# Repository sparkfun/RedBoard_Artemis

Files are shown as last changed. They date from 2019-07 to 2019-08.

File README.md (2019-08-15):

SparkFun RedBoard Artemis
============================

SparkFun RedBoard Artemis  
[*SparkFun RedBoard (DEV-15444)*](https://www.sparkfun.com/products/15444)

Think of the RedBoard Artemis as just another Arduino... That has BLE. And one meg of flash. And runs at less than 1mA. Oh, and it can run TensorFlow models. Ya, that too. The RedBoard Artemis takes the incredibly powerful Artemis module from SparkFun and wraps it up in an easy to use and familiar Uno footprint. We've written an Arduino core from scratch to make programming the Artemis as familiar as `Serial.begin(9600)`. Time-to-first-blink is less than five minutes.

The RedBoard Artemis has the improved power conditioning and USB to serial that we've refined over the years on our RedBoard line of products. A modern USB-C connector makes programming easy. A Qwiic connector makes I<sup>2</sup>C easy. The RedBoard Artemis is fully compatible with SparkFun's Arduino core and can be programmed easily under the Arduino IDE. We've exposed the JTAG connector for more advanced users who prefer to use the power and speed of professional tools. We've added a digital MEMS microphone for folks wanting to experiment with always-on voice commands with TensorFlow and machine learning. We've even added a convenient jumper to measure current consumption for low power testing.

With 1M flash and 384k RAM you'll have plenty of room for your sketches. The Artemis module runs at 48MHz with a 96MHz turbo mode available and with Bluetooth to boot!

The SparkFun RedBoard Artemis is a great platform to 'kick the tires' of this amazing module. If you're interesting in testing out the full capabilities of the SparkFun Artemis module or if you're looking for more compact solution, be sure to checkout our ATP and Nano versions of the Artemis line.

Repository Contents
-------------------
* **/Hardware** - Eagle design files (.brd, .sch)

Documentation
-------------------
* **[Hookup Guide for the RedBoard Artemis](https://learn.sparkfun.com/tutorials/hookup-guide-for-the-sparkfun-redboard-artemis)**
* **[Artemis Development with Arduino](https://learn.sparkfun.com/tutorials/artemis-development-with-arduino)**
* **[Ambiq Apollo3 SDK SetUp](https://learn.sparkfun.com/tutorials/using-sparkfun-edge-board-with-ambiq-apollo3-sdk)**
* **[Designing with the SparkFun Artemis](https://learn.sparkfun.com/tutorials/designing-with-the-sparkfun-artemis)**
* **[CH340E USB to serial IC Drivers](https://www.sparkfun.com/ch340)**

License Information
-------------------

This product is _**open source**_! 

Please review the LICENSE.md file for license information. 

If you have any questions or concerns on licensing, please contact techsupport@sparkfun.com.

Please use, reuse, and modify these files as you see fit. Please maintain attribution to SparkFun Electronics and release any derivative under the same license.

Distributed as-is; no warranty is given.

- Your friends at SparkFun.

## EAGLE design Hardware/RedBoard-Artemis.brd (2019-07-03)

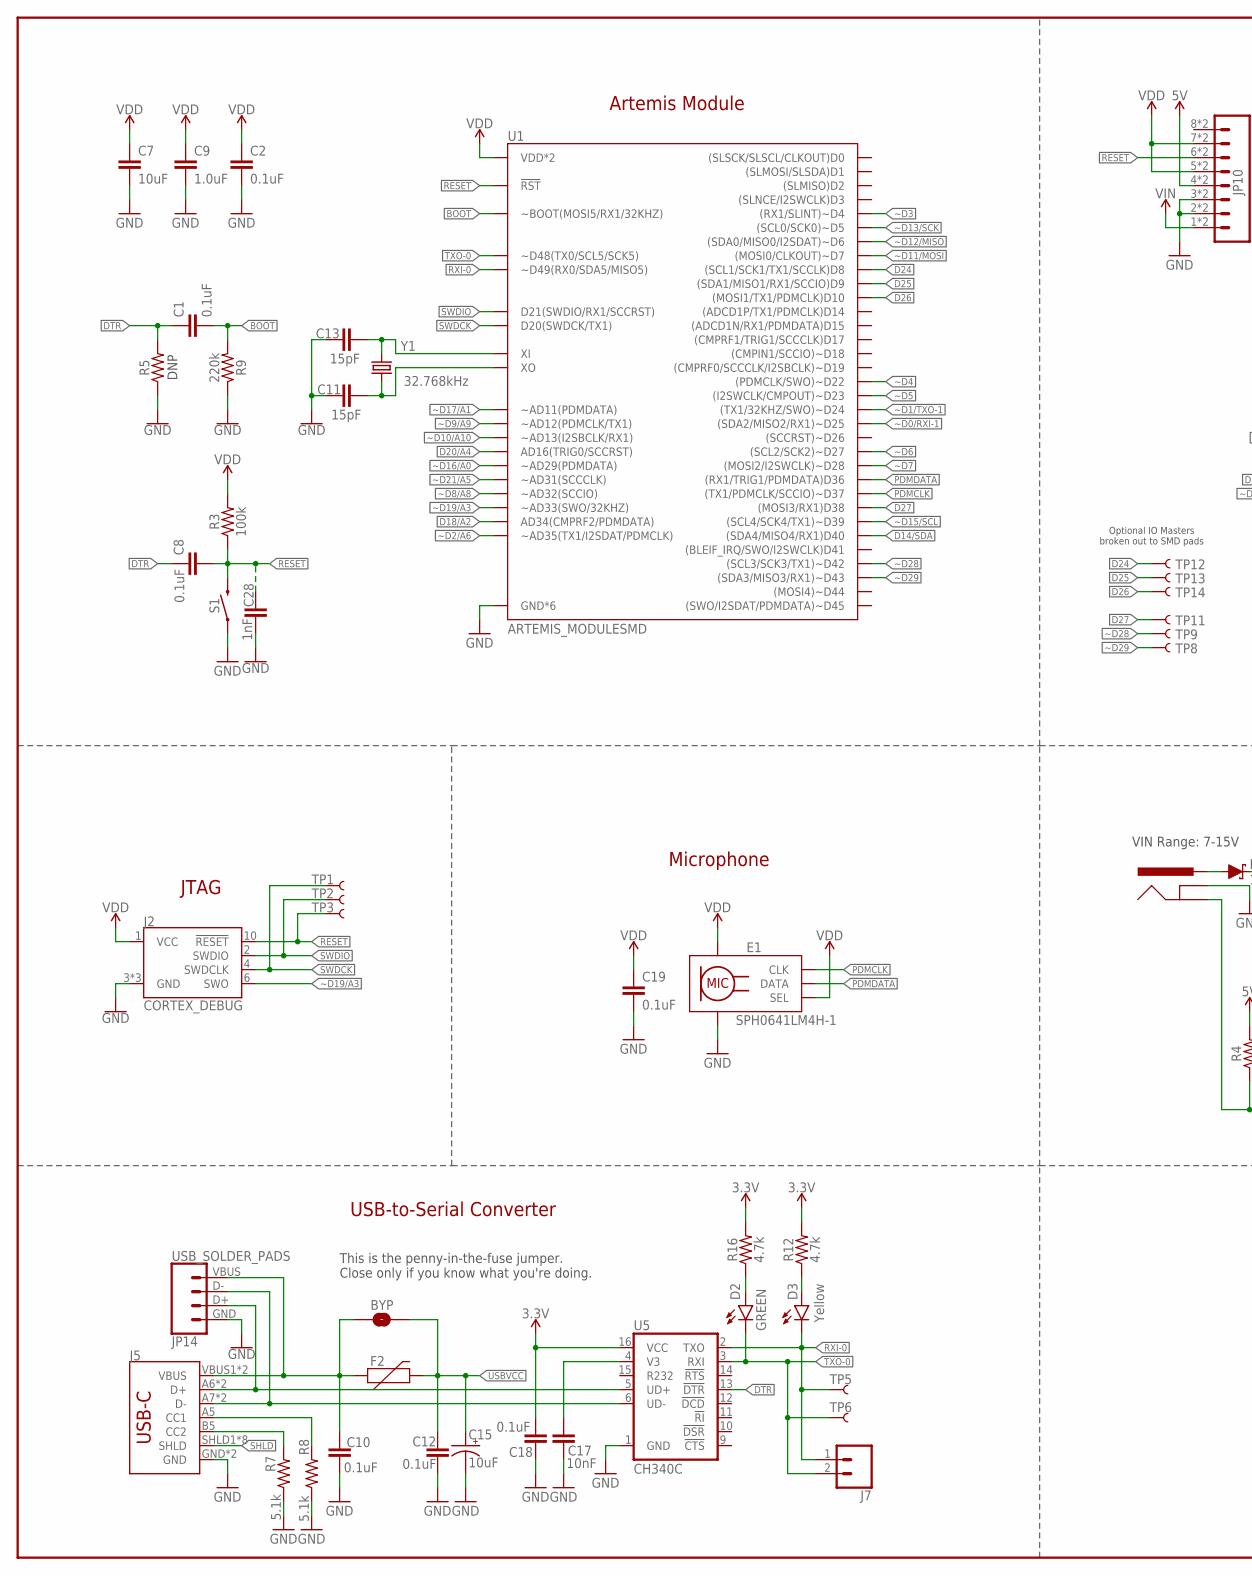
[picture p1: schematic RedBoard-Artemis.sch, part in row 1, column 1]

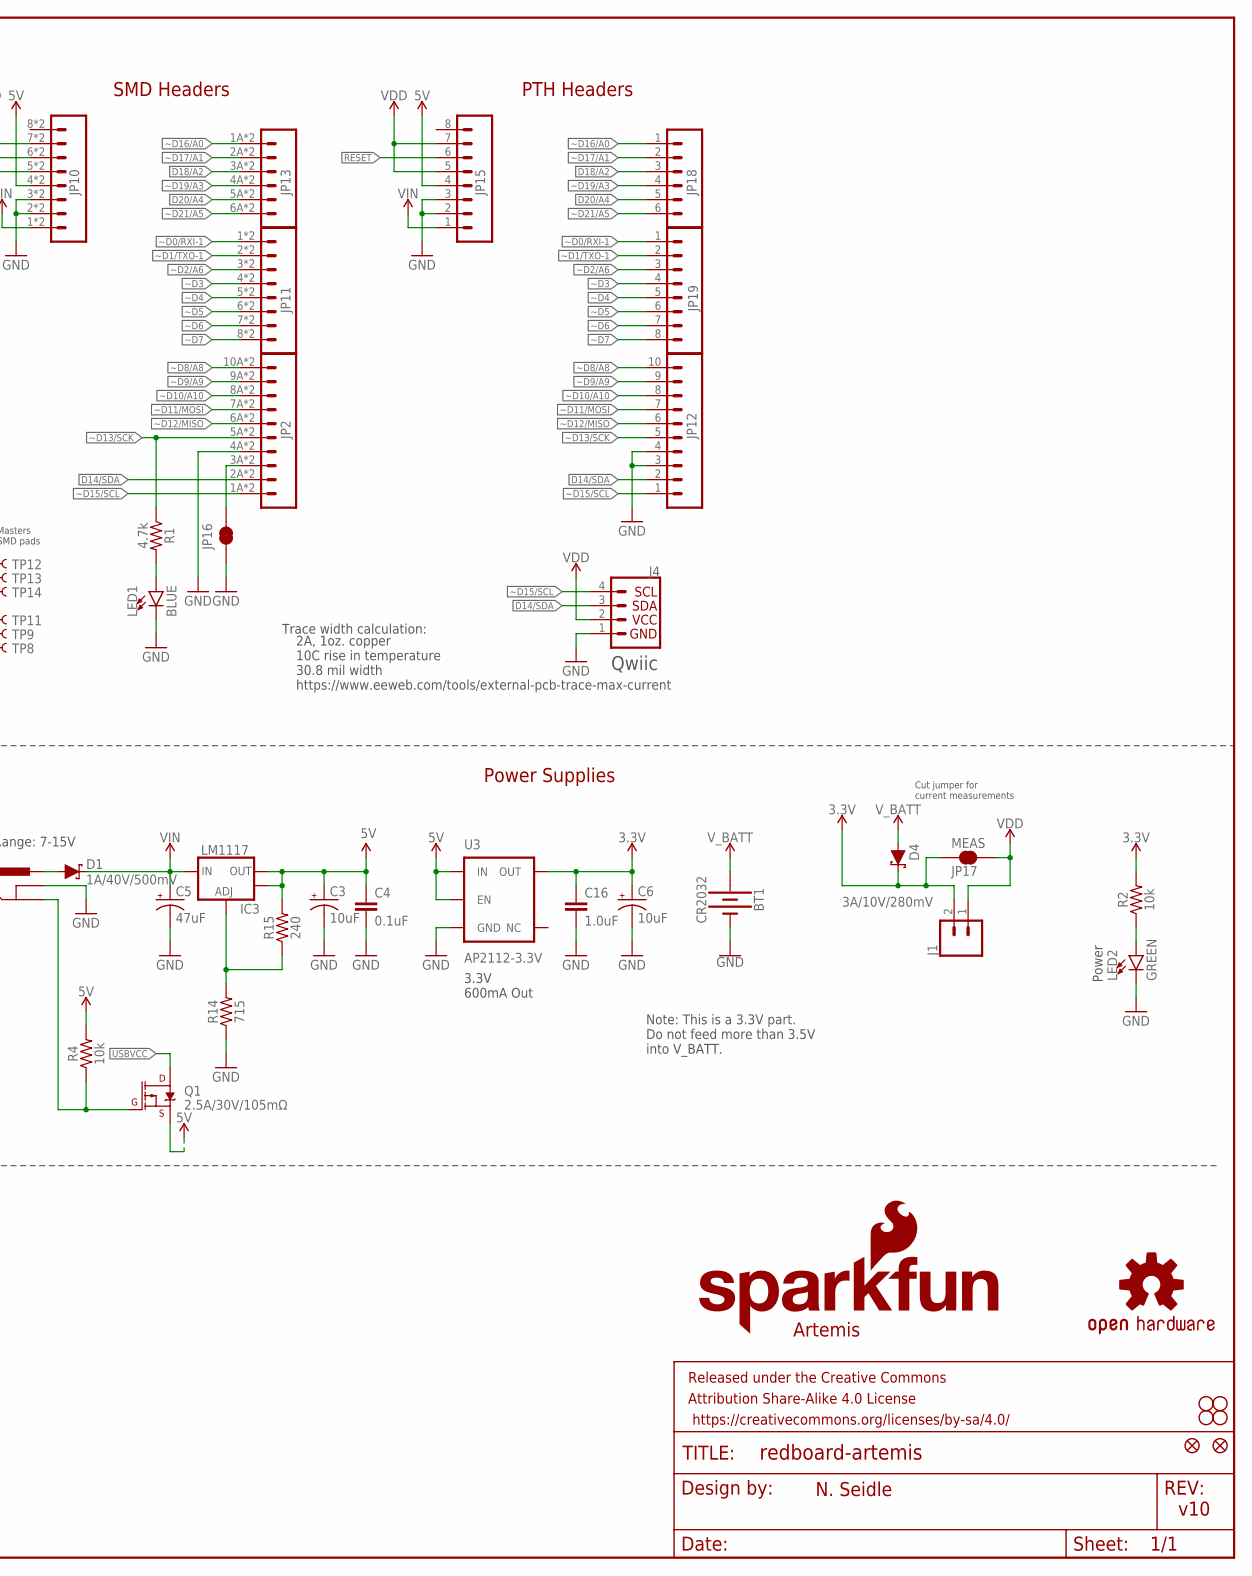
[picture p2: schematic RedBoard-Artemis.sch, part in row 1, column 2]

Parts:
BT1: CR2032; BATTCON_20MM_4LEGS_OVERPASTE
BYP: JUMPER-SMT_2_NO_SILK; SMT-JUMPER_2_NO_SILK
C1, C2, C4, C8, C10, C12, C18, C19: 0.1uF; 0603
C3, C6, C15: 10uF; EIA3216
C5: 47uF; PANASONIC_D
C7: 10uF; 0603
C9, C16: 1.0uF; 0603
C11, C13: 15pF; 0603
C17: 10nF; 0603
C28: 1nF; 0603
D1: 1A/40V/500mV; SMA-DIODE
D2: GREEN; LED-1206
D3: Yellow; LED-1206
D4: 3A/10V/280mV; SOD-323
E1: SPH0641LM4H-1; SPH0641LM4H-1_MICROPHONE
F2: 6V/2A; 1210
FRAME3: FRAME-LEDGER; CREATIVE_COMMONS
IC3: LM1117; SOT223-ALT1
J1, J7: CONN_021X02_NO_SILK; 1X02_NO_SILK
J2: CORTEX_DEBUG; 2X5-PTH-1.27MM-NO_SILK
J3: POWER_JACKTOE; POWER_JACK_SMD_OVERPASTE_TOE
J4: QWIIC_CONNECTORJS-1MM; JST04_1MM_RA
J5: USB-C; USB-C-16P
JP1: SFE_LOGO_NAME.1_INCH; SFE_LOGO_NAME_.1
JP2: M10SMD_COMBO; 1X10_SMD_COMBINED
JP3, JP4, JP5, JP6: STAND-OFF
JP7: SFE_LOGO_FLAME.1_INCH; SFE_LOGO_FLAME_.1
JP8, JP9: FIDUCIAL1X2; FIDUCIAL-1X2
JP10: CONN_08SMD-COMBO-FEMALE_NC; 1X08_SMD_COMBINED_NC
JP11: JP11; 1X08_SMD_COMBINED_NC
JP12: M10NO_SILK; 1X10_NO_SILK
JP13: M06SMD-STRAIGHT-COMBO; 1X06_SMD_STRAIGHT_COMBO
JP14: USB_SOLDER_PADS; USB-SOLDER-PADS
JP15: M08NO_SILK; 1X08_NO_SILK@1
JP16: JUMPER-SMT_2_NC_TRACE_SILK; SMT-JUMPER_2_NC_TRACE_SILK
JP17: MEAS; SMT-JUMPER_2_NC_TRACE_SILK
JP18: M06NO_SILK; 1X06_NO_SILK@1
JP19: CONN_08NO_SILK_FEMALE_PTH; 1X08_NO_SILK
LED1: BLUE; LED-1206
LED2: GREEN; LED-1206
Q1: 2.5A/30V/105mΩ; SOT23-3
R1, R12, R16: 4.7k; 0603
R2, R4: 10k; 0603
R3: 100k; 0603
R5: 0603
R7, R8: 5.1k; 0603
R9: 220k; 0603
R14: 715; 0603
R15: 240; 0603
S1: MOMENTARY-SWITCH-SPST-SMD-5.2-TALL-REDUNDANT; TACTILE_SWITCH_SMD_5.2MM
TP1, TP2, TP3, TP5, TP6, TP8, TP9, TP11, TP12, TP13, TP14: TEST-POINT3X5; PAD.03X.05
U1: ARTEMIS_MODULESMD; ARTEMIS_FP
U3: AP2112-3.3V; SOT23-5
U5: CH340C; SO016
U$16: OSHW-LOGOS; OSHW-LOGO-S
Y1: 32.768kHz; CRYSTAL-SMD-3.2X1.5MM

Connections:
3.3V: C6.+, C16.1, C18.1, D4.C, J1.2, JP17.1, R2.2, R12.2, R16.2, U3.5 (OUT), U5.16 (VCC)
5V: C3.+, C4.1, IC3.2 (OUT), IC3.4 (OUT), JP10.4, JP10.4@2 (4), JP15.4, Q1.2 (S), R4.2, R15.2, U3.1 (IN), U3.3 (EN)
!DTR: C1.1, C8.1, R5.2, U5.13 (!DTR)
!RESET: C8.2, C28.1, J2.10 (!RESET), JP10.6, JP10.6@2 (6), JP15.6, R3.1, S1.3 (2), S1.4 (2), TP3.P$1, U1.~RST (!RST)
BOOT: C1.2, R9.2, U1.BOOT (~BOOT(MOSI5/RX1/32KHZ))
CC1: J5.A5 (CC1), R8.2
CC2: J5.B5 (CC2), R7.2
D14/SDA: J4.3, JP2.2A (2), JP2.2B (2), JP12.2, U1.D40 ((SDA4/MISO4/RX1)D40)
D18/A2: JP13.3A (3), JP13.3B (3), JP18.3, U1.AD34 (AD34(CMPRF2/PDMDATA))
D20/A4: JP13.5A (5), JP13.5B (5), JP18.5, U1.AD16 (AD16(TRIG0/SCCRST))
D24: TP12.P$1, U1.D8 ((SCL1/SCK1/TX1/SCCLK)D8)
D25: TP13.P$1, U1.D9 ((SDA1/MISO1/RX1/SCCIO)D9)
D26: TP14.P$1, U1.D10 ((MOSI1/TX1/PDMCLK)D10)
D27: TP11.P$1, U1.D38 ((MOSI3/RX1)D38)
D+: J5.A6 (D+), J5.B6 (D+), JP14.D+ (3), U5.5 (UD+)
D-: J5.A7 (D-), J5.B7 (D-), JP14.D- (2), U5.6 (UD-)
GND: BT1.2 (-), C2.1, C3.-, C4.2, C5.-, C6.-, C7.2, C9.2, C10.2, C11.1, C12.2, C13.1, C15.-, C16.2, C17.2, C18.2, C19.2, C28.2, E1.3 (GND), E1.6 (GND), E1.7 (GND), E1.8 (GND), J2.3 (GND), J2.5 (GND), J2.9 (GND), J3.GND (GNDBREAK), J4.1, J5.GND, J5.GND2 (GND), JP2.4A (4), JP2.4B (4), JP10.2, JP10.2@2 (2), JP10.3, JP10.3@2 (3), JP12.3, JP12.4, JP14.GND (4), JP15.2, JP15.3, JP16.1, LED1.C, LED2.C, R5.1, R7.1, R8.1, R9.1, R14.1, S1.1, S1.2 (1), U1.GND@1 (GND*6), U1.GND@22 (GND*6), U1.GND@38 (GND*6), U1.GND@39 (GND*6), U1.GND@47 (GND*6), U1.GND@59 (GND*6), U3.2 (GND), U5.1 (GND)
INSERT: J3.P$4 (GND), Q1.1 (G), R4.1
unnamed: LED1.A, R1.2
unnamed: LED2.A, R2.1
unnamed: D2.A, R16.1
unnamed: C17.1, U5.4 (V3)
unnamed: C11.2, U1.XO, Y1.P$2 (2)
unnamed: C13.2, U1.XI, Y1.P$1 (1)
unnamed: D3.A, R12.1
unnamed: JP2.3A (3), JP2.3B (3), JP16.2
unnamed: IC3.1 (ADJ), R14.2, R15.1
PDMCLK: E1.4 (CLK), U1.~D37 ((TX1/PDMCLK/SCCIO)~D37)
PDMDATA: E1.1 (DATA), U1.D36 ((RX1/TRIG1/PDMDATA)D36)
PWRIN: D1.A, J3.VIN0 (PWR)
RXI-0: D3.C, J7.1, TP5.P$1, U1.RXI-0 (~D49(RX0/SDA5/MISO5)), U5.2 (TXO)
SHLD: J5.SHLD1 (SHLD), J5.SHLD2 (SHLD), J5.SHLD3 (SHLD), J5.SHLD4 (SHLD), J5.SHLD5 (SHLD), J5.SHLD6 (SHLD), J5.SHLD7 (SHLD), J5.SHLD8 (SHLD)
SWDCK: J2.4 (SWDCLK), TP1.P$1, U1.SWDCK (D20(SWDCK/TX1))
SWDIO: J2.2 (SWDIO), TP2.P$1, U1.SWDIO (D21(SWDIO/RX1/SCCRST))
TXO-0: D2.C, J7.2, TP6.P$1, U1.TXO-0 (~D48(TX0/SCL5/SCK5)), U5.3 (RXI)
USBVCC: BYP.2, C12.1, C15.+, F2.2, Q1.3 (D)
VDD: C2.2, C7.1, C9.1, C19.1, E1.2 (SEL), E1.5 (VDD), J1.1, J2.1 (VCC), J4.2, JP10.5, JP10.5@2 (5), JP10.7, JP10.7@2 (7), JP15.5, JP15.7, JP17.2, R3.2, U1.VDD@36 (VDD*2), U1.VDD@37 (VDD*2)
VIN: C5.+, D1.C, IC3.3 (IN), JP10.1, JP10.1@2 (1), JP15.1
VUSB: BYP.1, C10.1, F2.1, J5.VBUS1 (VBUS), J5.VBUS2 (VBUS), JP14.VBUS (1)
V_BATT: BT1.1 (+), D4.A
~D0/RXI-1: JP11.1, JP11.1@2 (1), JP19.1, U1.~D25 ((SDA2/MISO2/RX1)~D25)
~D1/TXO-1: JP11.2, JP11.2@2 (2), JP19.2, U1.~D24 ((TX1/32KHZ/SWO)~D24)
~D2/A6: JP11.3, JP11.3@2 (3), JP19.3, U1.~AD35 (~AD35(TX1/I2SDAT/PDMCLK))
~D3: JP11.4, JP11.4@2 (4), JP19.4, U1.~D4 ((RX1/SLINT)~D4)
~D4: JP11.5, JP11.5@2 (5), JP19.5, U1.~D22 ((PDMCLK/SWO)~D22)
~D5: JP11.6, JP11.6@2 (6), JP19.6, U1.~D23 ((I2SWCLK/CMPOUT)~D23)
~D6: JP11.7, JP11.7@2 (7), JP19.7, U1.~D27 ((SCL2/SCK2)~D27)
~D7: JP11.8, JP11.8@2 (8), JP19.8, U1.~D28 ((MOSI2/I2SWCLK)~D28)
~D8/A8: JP2.10A (10), JP2.10B (10), JP12.10, U1.~AD32 (~AD32(SCCIO))
~D9/A9: JP2.9A (9), JP2.9B (9), JP12.9, U1.~AD12 (~AD12(PDMCLK/TX1))
~D10/A10: JP2.8A (8), JP2.8B (8), JP12.8, U1.~AD13 (~AD13(I2SBCLK/RX1))
~D11/MOSI: JP2.7A (7), JP2.7B (7), JP12.7, U1.D7 ((MOSI0/CLKOUT)~D7)
~D12/MISO: JP2.6A (6), JP2.6B (6), JP12.6, U1.~D6 ((SDA0/MISO0/I2SDAT)~D6)
~D13/SCK: JP2.5A (5), JP2.5B (5), JP12.5, R1.1, U1.~D5 ((SCL0/SCK0)~D5)
~D15/SCL: J4.4, JP2.1A (1), JP2.1B (1), JP12.1, U1.~D39 ((SCL4/SCK4/TX1)~D39)
~D16/A0: JP13.1A (1), JP13.1B (1), JP18.1, U1.~AD29 (~AD29(PDMDATA))
~D17/A1: JP13.2A (2), JP13.2B (2), JP18.2, U1.~AD11 (~AD11(PDMDATA))
~D19/A3: J2.6 (SWO), JP13.4A (4), JP13.4B (4), JP18.4, U1.~AD33/SWO (~AD33(SWO/32KHZ))
~D21/A5: JP13.6A (6), JP13.6B (6), JP18.6, U1.~AD31 (~AD31(SCCCLK))
~D28: TP9.P$1, U1.~D42 ((SCL3/SCK3/TX1)~D42)
~D29: TP8.P$1, U1.~D43 ((SDA3/MISO3/RX1)~D43)

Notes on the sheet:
Artemis
USB-to-Serial Converter
N. Seidle
v10
This is the penny-in-the-fuse jumper. Close only if you know what you're doing.
Optional IO Masters broken out to SMD pads
Artemis Module
SMD Headers
DNP
PTH Headers
VIN Range: 7-15V
3.3V 600mA Out
Cut jumper for current measurements
Power Supplies
Note: This is a 3.3V part. Do not feed more than 3.5V into V_BATT.
Power
Microphone
Qwiic
Trace width calculation:
2A, 1oz. copper 10C rise in temperature 30.8 mil width https://www.eeweb.com/tools/external-pcb-trace-max-current
JTAG

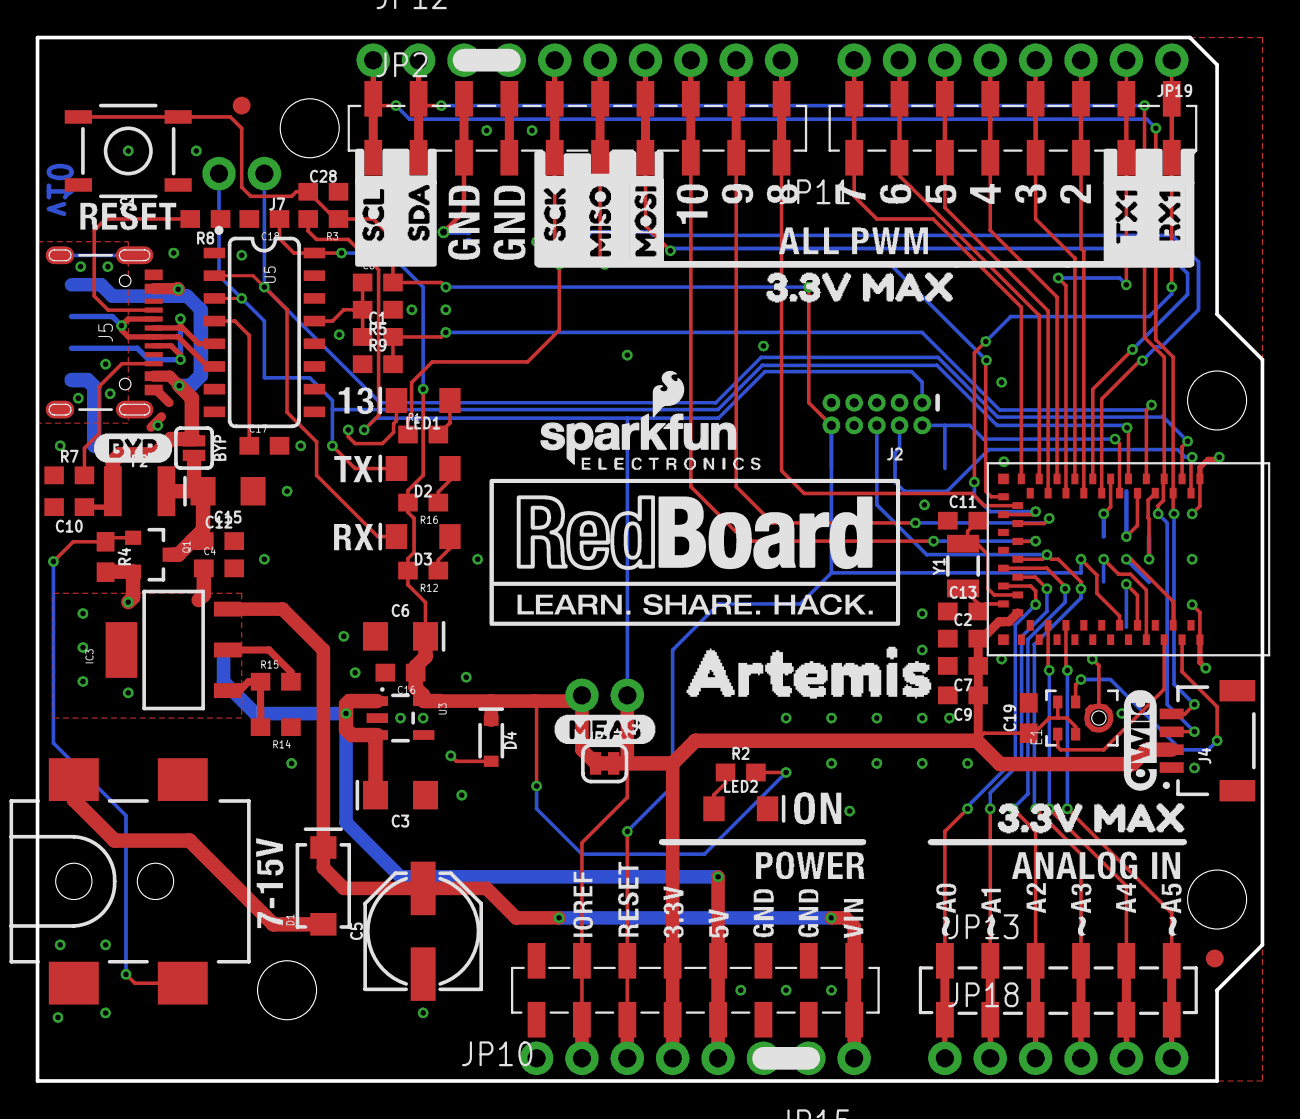
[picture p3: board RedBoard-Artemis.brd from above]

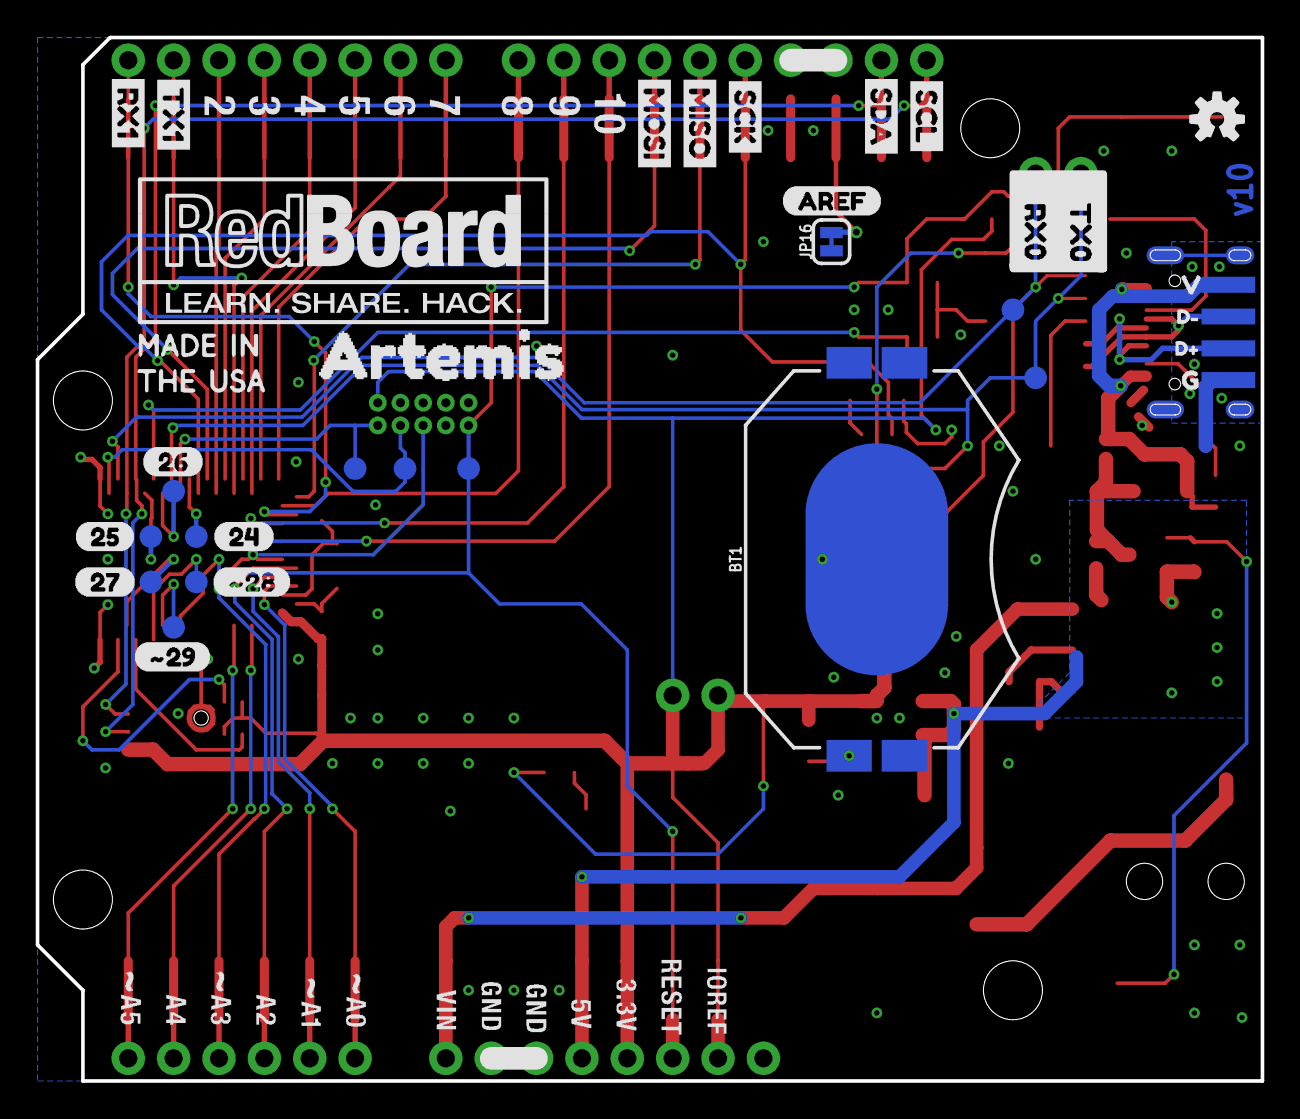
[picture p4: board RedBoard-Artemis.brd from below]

Board: 2 copper layers, 68.6 x 58.4 mm, 122 parts (38 on the bottom side), 61 nets.

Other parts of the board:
FRAME2: FRAME-LETTERNO_PACKAGE; DUMMY
U$1, U$18: SCL1
U$2: D#3
U$3, U$22: SDA0
U$4: MADEINUSA#PNG
U$9: QWIIC_COPYRIGHT_SMALL
U$10: D#4
U$11: G1
U$12: V0
U$13, U$67: 3#3V_MAX2
U$14, U$15: ARTEMIS0
U$17: #284
U$19: #295
U$20: AREF2
U$21: 240
U$23: 251
U$24: 262
U$25: 273
U$26, U$50: SCK9
U$27, U$47: MISO8
U$28, U$48: MOSI7
U$29, U$72: TX10
U$30, U$71: RX11
U$49: RX01
U$53: TX00
U$68: BYP0
U$70: MEAS3

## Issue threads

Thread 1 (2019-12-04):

Expose ITM/SWO pin on SWD/JTAG Connector

oclyke, 2019-12-04:
Will you consider adding a free ITM/SWO pin to the SWD/JTAG connector as is demonstrated on the [Edge](https://cdn.sparkfun.com/assets/2/b/7/4/d/SparkFun_Edge_Schematic.pdf) board? This affords users a different ('pro') way to do debug printing and possibly frees up a UART for another purpose. Inspired by https://github.com/sparkfun/SparkFun_Apollo3_AmbiqSuite_BSPs/issues/19

oclyke, 2019-12-13:
OOPS. I totally overlooked the SWO pin here and made all this fuss over nothing. Sorry!

Closed 2019-12-13.

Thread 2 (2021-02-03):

Reading from A0 reads from A4 instead

fathat, 2021-02-03:
This very basic example code:

`
// the setup routine runs once when you press reset:
void setup() {
  // initialize serial communication at 9600 bits per second:
  Serial.begin(9600);
}

// the loop routine runs over and over again forever:
void loop() {
  // read the input on analog pin 0:
  int sensorValue = analogRead(A0);
  // print out the value you read:
  Serial.println(sensorValue);
  delay(1);        // delay in between reads for stability
}`

Plugging a joystick into A0 does not work.. however A4 here works fine. The correct board and com port are selected in the arduino IDE. If I plug in pin indexes directly, I can use 16 (A4) and 11 (A1), and.. otherwise the graphical data sheet doesn't seem to match up with the other pins and I can't get them to work. Help?

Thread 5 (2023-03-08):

strange choice of pinouts?

jerabaul29, 2023-03-08:
Hi,

Something i noted recently: the builtin LED is on pin 13, which is also the pin for the SPI SCK. This leads to plenty of weird consequences when trying for example to blink and use SPI at the same time. Maybe in future board it could be useful to put the builtin LED on a pin that is not used for anything else important by default? :)

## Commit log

2019-07-02 Move measurement PTH from under CR2032.
    [RedBoard-Artemis.brd, RedBoard-Artemis.sch]
2019-07-02 Rename silk to RedBoard. Change version to v10.
    [RedBoard-Artemis.brd, RedBoard-Artemis.sch]
2019-07-02 Silk adjust
    [RedBoard-Artemis.brd]
2019-07-02 Remove diode from 3.3V rail. Move MEAS jumper.
    [RedBoard-Artemis.brd, RedBoard-Artemis.sch]
2019-07-02 Add PTH connectors to edges of board.
    [RedBoard-Artemis.brd, RedBoard-Artemis.sch]
2019-07-03 Add bottom silk indicators. Move MEAS jumper.
    [RedBoard-Artemis.brd, RedBoard-Artemis.sch]
2019-07-03 Approved DRC errors
    [RedBoard-Artemis.brd, RedBoard-Artemis.sch]
2019-07-03 Adding production panels
    [RedBoard-Artemis-Panel.GBL, RedBoard-Artemis-Panel.GBO, RedBoard-Artemis-Panel.GBP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]
2019-07-03 Adding designed by text
    [RedBoard-Artemis.brd]

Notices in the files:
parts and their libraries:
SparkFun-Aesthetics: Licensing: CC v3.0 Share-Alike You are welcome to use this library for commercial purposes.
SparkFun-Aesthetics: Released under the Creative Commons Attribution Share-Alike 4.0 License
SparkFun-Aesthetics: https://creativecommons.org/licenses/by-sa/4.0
